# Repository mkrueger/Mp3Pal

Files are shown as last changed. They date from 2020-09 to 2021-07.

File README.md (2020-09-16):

# MP3Pal
MP3 player for kids based tonunio and Hörbert design.



## Features

 * Plays audio from a SD Card
 * Select playlists via 12 buttons and rfid tags

## Part list

* Arduino Nano
* DFPlayer mini
* Speaker Visaton FR 10 HM
* Guitar Potentiometer
* 74HC238, 74HC153
* 9 Arcade buttons + 3 Acracde buttons with LED
* AZDelivery Battery Expansion Shield 18650
* 18650 Battery
* Göldo Dome Chrome
* Handle from DIY Store
* Resistors 5x 10k, 1x 1k, 3x 100
* 1 Capacitor 100 uF (optional)
* RFID tags, magnets and figures
* Threads for 3D prints (I use the ones from Ruthex) M2, M3, M4
* Wires
  - JST 2.5 Connectors & Wires
  - Mini Micro JST 2.0 (with cables & pin connectors)

… to be continued (but it's below 100 Euro - if you get it from ali express it's maybe ~50)

## Schematic
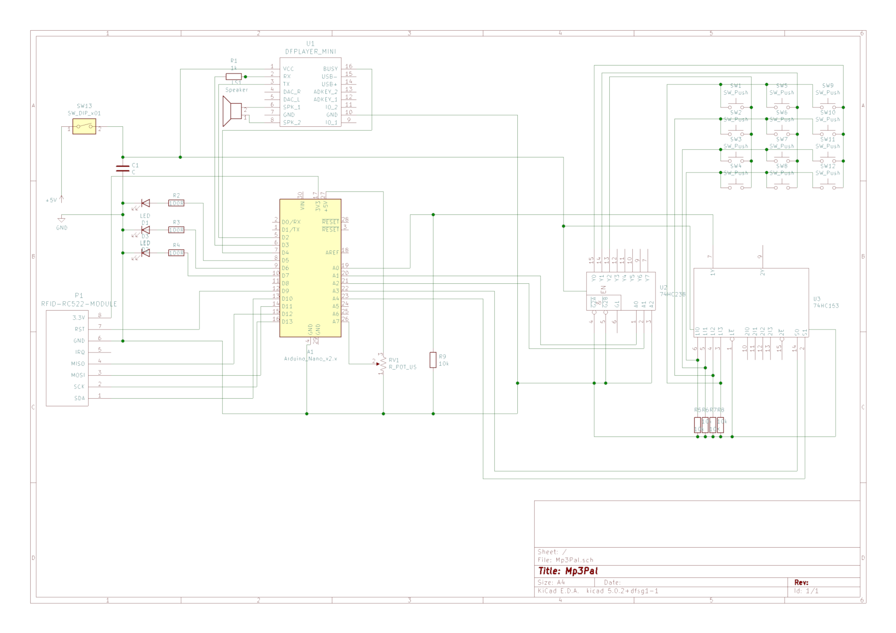
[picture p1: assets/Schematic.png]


## Alternatives

Tonunio

https://www.voss.earth/tonuino/

KidsMP3Player

https://github.com/ghmartin77/KidsMP3Player

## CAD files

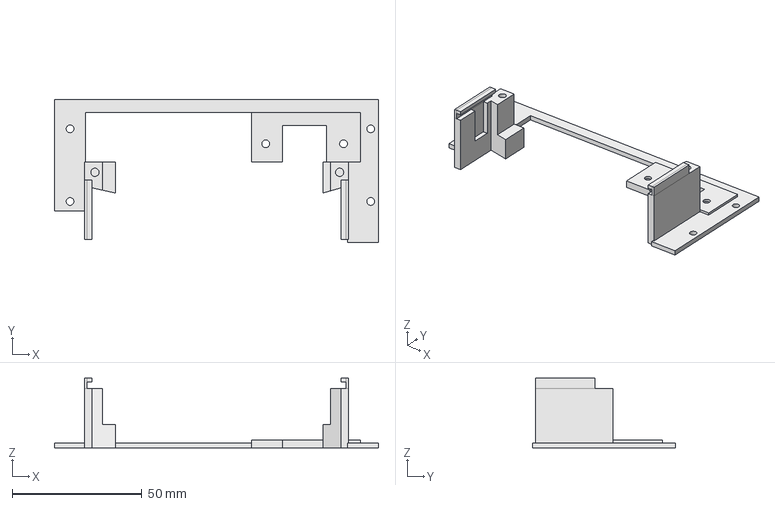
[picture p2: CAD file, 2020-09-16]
CAD_Files/v1/BattryMount.FCStd
125.0 x 55.0 x 27.0 mm

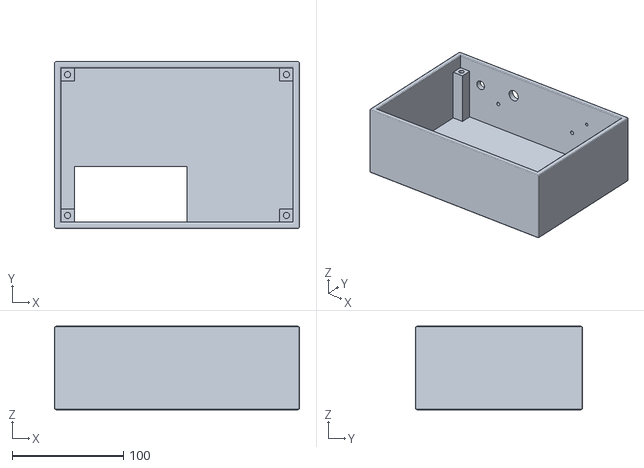
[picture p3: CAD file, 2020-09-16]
Production/Chassis.stl
220.0 x 150.0 x 75.0

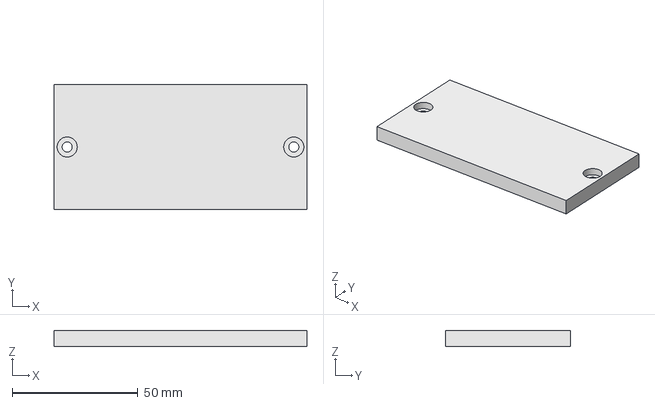
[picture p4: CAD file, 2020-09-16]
CAD_Files/v1/Backplate.FCStd
100.5 x 49.5 x 6.50 mm

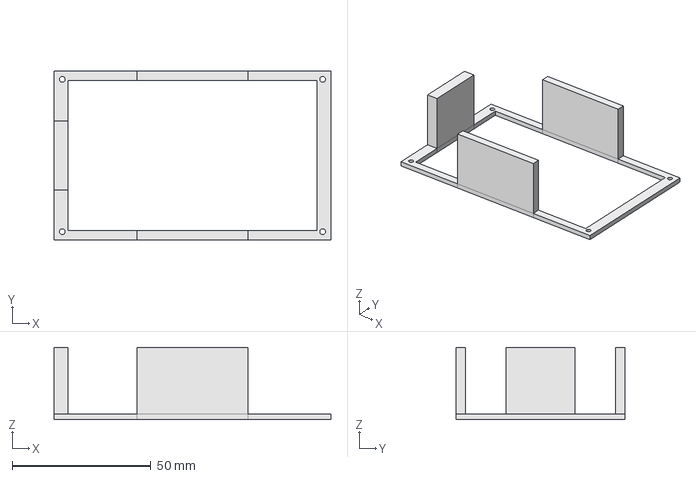
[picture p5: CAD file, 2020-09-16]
CAD_Files/v1/PcbMount.FCStd
100.0 x 61.0 x 26.0 mm

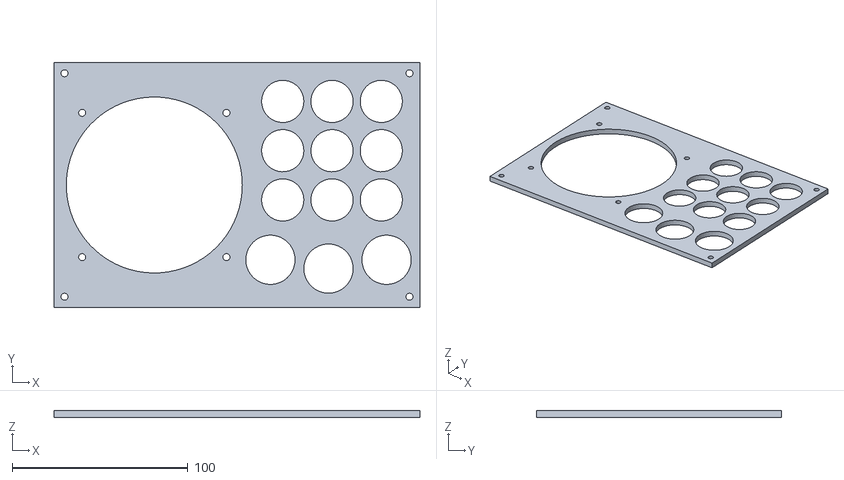
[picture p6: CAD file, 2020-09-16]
Production/Frontplate.stl
208.0 x 139.0 x 4.00

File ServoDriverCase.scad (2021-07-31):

include <arduino/arduino.scad>

$fn=40;
wallsize=4;

boxW=84+wallsize;
boxL=106+wallsize;
boxH=25;

minkowski()
{
    translate([-boxW/2,-boxL/2,0])
    {
       difference() {
           difference() {
              cube([boxW,boxL,boxH], center=false);
              translate([boxW-27,boxL-wallsize-1,7])
                cube([16,wallsize+6, boxH]);
              translate([boxW-55,boxL-wallsize-1,7])
                cube([12,wallsize+2, boxH]);
           }
            translate([wallsize,wallsize,wallsize])
                cube([boxW-wallsize*2,boxL-wallsize*2,boxH], center=false);
        }
    }
    sphere(1);
}

difference() {
    translate([0, 0, boxH])
        cube([boxW-wallsize,boxL-wallsize, wallsize*2], center=true);
    
    translate([0, 0, boxH+0.1])
        cube([boxW-wallsize*2,boxL-wallsize*2, wallsize*2+0.3], center=true);
}

translate ([boxW/2-wallsize,boxL/2-wallsize,0]) {
    rotate(a=[0,0,180]) {
        translate([2.54,15.24,wallsize])
            mount();
        translate([50.8,13.97,wallsize])
            mount();
        translate([2.54,90.17,wallsize])
            mount();
        translate([50.8,96.52,wallsize])
            mount();
        /*
        translate([0,0,wallsize+5])
            arduino(MEGA);*/
    }
}

translate ([4-boxW/2 + wallsize,62+-boxL+wallsize,0]) {
        translate([0,0,wallsize])
            mount();
        translate([18,0,wallsize])
            mount();
        translate([0,55,wallsize])
            mount();
        translate([18,55,wallsize])
            mount();
}
module mount() {
    difference() {
        cylinder(h=5,d=3.2 + 1.4 * 2);
        translate([0, 0, 1.1])
            cylinder(h=4.1, d=3.2);
    }
}

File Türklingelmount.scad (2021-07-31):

$fn=100;

backplateHeight=184;
backplateWidth=105;

depth  = 2;

difference()
{
    cube([backplateWidth, backplateHeight, depth], center = true);
    translate([-55 / 2, -142 / 2, 0])
        cylinder(depth, r=2, center = true);
    translate([55 / 2, -142 / 2, 0])
        cylinder(depth, r=2, center = true);
    translate([-55 / 2, 142 / 2, 0])
        cylinder(depth, r=2, center = true);
    translate([55 / 2,  142 / 2, 0])
        cylinder(depth, r=2, center = true);
    
   translate([0, -68 / 2, 0])
        cylinder(depth, r=2, center = true);
   translate([0, 68 / 2, 0])
        cylinder(depth, r=2, center = true);
   
    cube([25, 30, depth], center = true);

}

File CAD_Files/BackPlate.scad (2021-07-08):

$fn=100;

spacing = 1;
backplateHeight=78;
backplateWidth=97;

depth  = 6;
sinkHeight = 3.5;

difference()
{
    cube([backplateWidth - spacing, backplateHeight - spacing , 4], center = true);
    translate([-backplateWidth / 2 + 6, 0, 0])
        cylinder(depth, r=2, center = true);
    translate([backplateWidth / 2 - 6, 0, 0])
        cylinder(depth, r=2, center = true);
   
    translate([0, 0, depth - sinkHeight])
    {
        translate([-backplateWidth / 2 + 6, 0, 0])
            cylinder(sinkHeight, r=4, center = true);
        translate([backplateWidth / 2 - 6, 0, 0])
            cylinder(sinkHeight, r=4, center = true);
    }

}

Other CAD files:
Production/Backplate.stl
CAD_Files/v1/Chassis.FCStd
Production/PcbMount.stl
CAD_Files/v1/Frontplate.FCStd
Production/BatteryMount.stl
CAD_Files/BatteryMount.scad
CAD_Files/Chassis.scad
CAD_Files/FrontPlate.scad
CAD_Files/Unbenannt.scad

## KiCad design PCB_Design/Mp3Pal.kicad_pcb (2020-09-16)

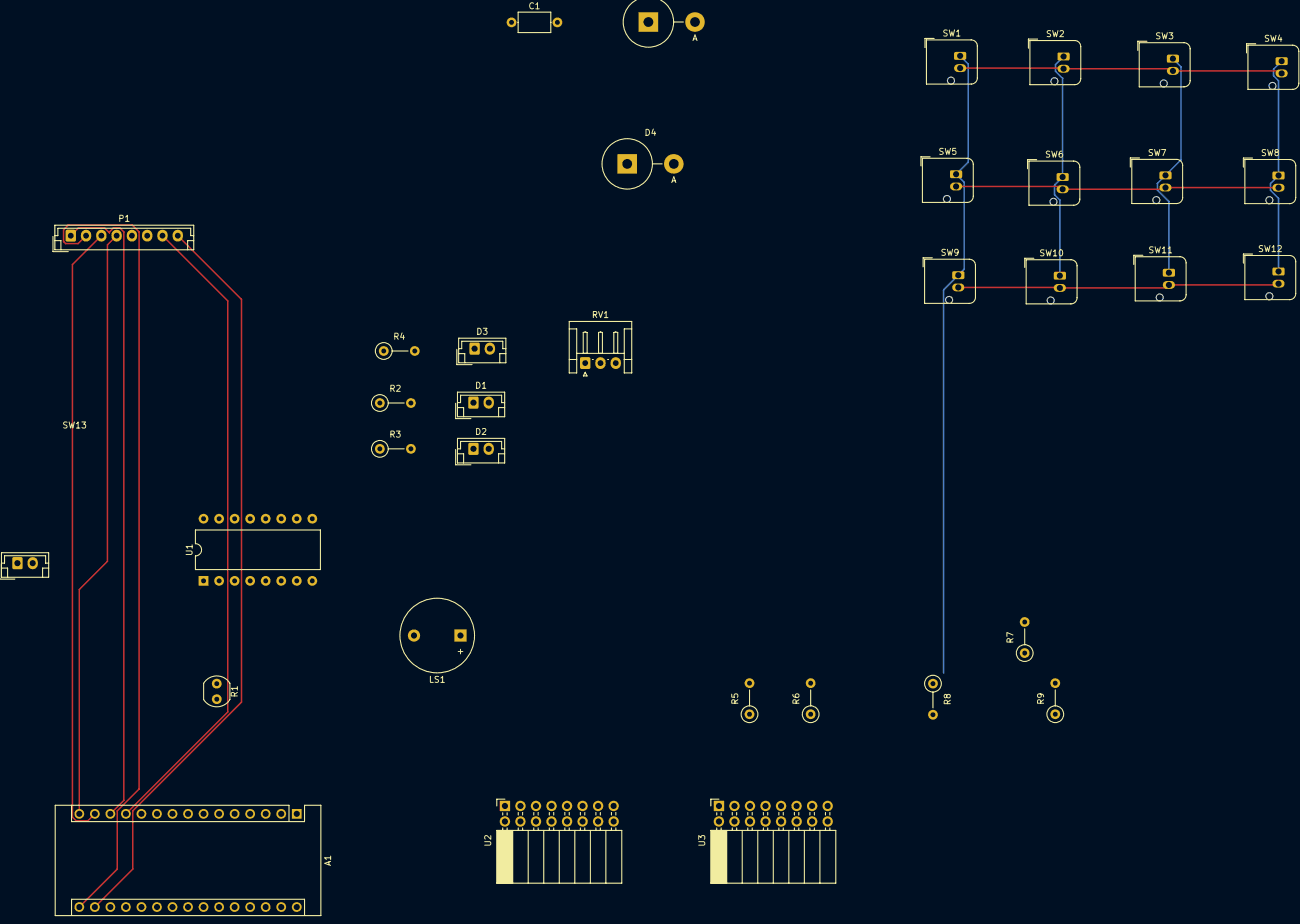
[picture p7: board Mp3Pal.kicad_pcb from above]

Board: 2 copper layers, 35 parts (0 on the bottom side), 34 nets.

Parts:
A1: Arduino_Nano_v2.x; Arduino_Nano
C1: C; C_Axial_L5.1mm_D3.1mm_P7.50mm_Horizontal
D1, D2, D3: LED; JST_EH_B2B-EH-A_1x02_P2.50mm_Vertical
D4, D5: D; D_5KPW_P7.62mm_Vertical_AnodeUp
LS1: Speaker; Buzzer_12x9.5RM7.6
P1: RFID-RC522-MODULE; JST_EH_B8B-EH-A_1x08_P2.50mm_Vertical
R1: 1k; R_LDR_4.9x4.2mm_P2.54mm_Vertical
R2, R3, R4: 100R; R_Axial_DIN0207_L6.3mm_D2.5mm_P5.08mm_Vertical
R5, R6, R8, R9: 10k; R_Axial_DIN0207_L6.3mm_D2.5mm_P5.08mm_Vertical
R7: R; R_Axial_DIN0207_L6.3mm_D2.5mm_P5.08mm_Vertical
RV1: R_POT_US; JST_EH_S3B-EH_1x03_P2.50mm_Horizontal
SW1, SW2, SW3, SW4, SW5, SW6, SW7, SW8, SW9, SW10, SW11, SW12: SW_Push; JST_JWPF_B02B-JWPF-SK-R_1x02_P2.00mm_Vertical
SW13: SW_DIP_x01; JST_EH_B2B-EH-A_1x02_P2.50mm_Vertical
U1: DFPLAYER_MINI; DIP-16_W10.16mm
U2: 74HC238; PinSocket_2x08_P2.54mm_Horizontal
U3: 74HC153; PinSocket_2x08_P2.54mm_Horizontal

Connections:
GND: A1.4, C1.2, D1.1, D2.1, D3.1, D4.1, D5.1, D5.2, R5.2, R6.2, R7.2, R8.2, R9.2, RV1.1, U2.3, U2.4, U2.5, U2.8, U3.1, U3.8
unnamed: A1.5, U1.3
unnamed: A1.6, R1.2
unnamed: A1.7, U1.16
unnamed: A1.9, R4.2
unnamed: A1.10, R3.2
unnamed: A1.11, R2.2
unnamed: A1.12, P1.7
unnamed: A1.13, P1.1
unnamed: A1.14, P1.3
unnamed: A1.15, P1.4
unnamed: A1.16, P1.2
unnamed: A1.17, P1.8
unnamed: A1.19, U2.1
unnamed: A1.20, U2.2
unnamed: A1.21, U3.14
unnamed: A1.22, U3.2
unnamed: A1.23, R9.1, U3.7
unnamed: A1.26, RV1.2
unnamed: D1.2, R2.1
unnamed: D2.2, R3.1
unnamed: D3.2, R4.1
unnamed: D4.2, U1.7
unnamed: LS1.1, U1.8
unnamed: LS1.2, U1.6
unnamed: R1.1, U1.2
unnamed: R5.1, SW4.1, SW8.1, SW12.1, U3.6
unnamed: R6.1, SW3.1, SW7.1, SW11.1, U3.5
unnamed: R7.1, SW2.1, SW6.1, SW10.1, U3.4
unnamed: R8.1, SW1.1, SW5.1, SW9.1, U3.3
unnamed: SW1.2, SW2.2, SW3.2, SW4.2, U2.13
unnamed: SW5.2, SW6.2, SW7.2, SW8.2, U2.14
unnamed: SW9.2, SW10.2, SW11.2, SW12.2, U2.15
VCC: A1.30, C1.1, P1.6, RV1.3, SW13.2, U1.1, U2.16, U3.16

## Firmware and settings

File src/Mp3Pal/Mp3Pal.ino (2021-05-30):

#include "Arduino.h"
#include "SoftwareSerial.h"
#include <DFMiniMp3.h>

#include <math.h>
#include <SPI.h>
#include <MFRC522.h>
#include "Parameters.h"

MFRC522 mfrc522(SS_PIN, RST_PIN); // Create MFRC522 instance.

SoftwareSerial mySoftwareSerial(2, 3);

int16_t currentTrack = -1;
int16_t currentFolder = -1;
int16_t trackCount;

bool isPause = false;
unsigned long nowMs;

class Mp3Notify;

static DFMiniMp3<SoftwareSerial, Mp3Notify> mp3Player(mySoftwareSerial);

#include "Functions.h"
#include "Volume.h"
#include "Keypad.h"

void setup()
{
  pinMode(LED_PAUSE_PIN, OUTPUT);
  digitalWrite(LED_PAUSE_PIN, HIGH);
  pinMode(LED_NEXT_PIN, OUTPUT);
  pinMode(LED_PREV_PIN, OUTPUT);

  pinMode(outPinA0, OUTPUT);
  pinMode(outPinA1, OUTPUT);
  pinMode(outPinS0, OUTPUT);
  pinMode(outPinS1, OUTPUT);
  pinMode(inPinY, INPUT);

  pinMode(PIN_VOLUME, INPUT);
  pinMode(PIN_BUSY, INPUT);

  mySoftwareSerial.begin(9600);
  Serial.begin(115200);
  SPI.begin();
  mfrc522.PCD_Init();
  mp3Player.begin();
/*  if (!mp3Player.begin(mySoftwareSerial))
  {
    Serial << F("Fatal error starting the mp3 player module.") << endl
           << F("Please restart.") << endl;
    errorMode();
  }
*/
  keyReadMs = volumeReadMs = millis();
  mp3Player.setVolume(7);
  volumeReadMs = -VOLUME_CHECK_TIMEOUT;

  Serial << F("MP3Pal online.") << endl;
  playStartAnimation();
}

void loop()
{
  nowMs = millis();
/*  if (mp3Player.available())
  {
    printDetail(mp3Player.readType(), mp3Player.read());
  }*/
  updateVolume();
  handleKeypress();
  scanRfid();
  delay(20);
}

/*
void printDetail(uint8_t type, int value)
{
  switch (type)
  {
  case TimeOut:
    Serial << F("Time Out!") << endl;
    mp3Player.reset();
    break;
  case WrongStack:
    Serial << F("Stack Wrong!") << endl;
    break;
  case DFPlayerCardInserted:
    Serial << F("Card Inserted!") << endl;
    break;
  case DFPlayerCardRemoved:
    Serial << F("Card Removed!") << endl;
    break;
  case DFPlayerCardOnline:
    Serial << F("Card Online!") << endl;
    break;
  case DFPlayerPlayFinished:
    Serial << F("Number:") << currentTrack << F(" Play Finished!");
    skipTrack();
    break;
  case DFPlayerError:
    Serial << F("DFPlayerError:");
    switch (value)
    {
    case Busy:
      Serial << F("Card not found");
      errorMode();
      break;
    case Sleeping:
      Serial << F("Sleeping");
      break;
    case SerialWrongStack:
      Serial << F("Get Wrong Stack");
      break;
    case CheckSumNotMatch:
      Serial << F("Check Sum Not Match");
      break;
    case FileIndexOut:
      Serial << F("File Index Out of Bound");
      break;
    case FileMismatch:
      Serial << F("Cannot Find File");
      break;
    case Advertise:
      Serial << F("In Advertise");
      break;
    default:
      Serial << F("Unknown");
      break;
    }
    Serial << endl;
    break;
  default:
    break;
  }
}
*/

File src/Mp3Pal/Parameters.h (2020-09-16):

#ifndef PARAMETERS_H
#define PARAMETERS_H


#define PIN_BUSY 4

#define LED_NEXT_PIN 6
#define LED_PREV_PIN 8
#define LED_PAUSE_PIN 7

#define SS_PIN 10
#define RST_PIN 9

#define endl F("\n")
template <class T>
inline Stream &operator<<(Stream &stream, T arg)
{
    stream.print(arg);
    return stream;
}

// hack: mp3Player.readFileCountsInFolder always returns - 1 so I hard coded the track counts
const int16_t TRACK_COUNT[] = {4, 4, 4, 5, 5, 5, 5, 5, 9, 3, 4, 5};

// Hard coded UID Tokens
String uidTags[] = {
  "79 E8 87 98",
  "BA 5F 3B 86"
};

const uint8_t uidPlaylists[] = { 10, 11};

#endif

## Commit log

2021-05-31 Worked on chassis design.
    [BackPlate.scad, Chassis.scad, FrontPlate.scad]
2021-07-08 Added old design, improved cad designs
    [BackPlate.scad, Backplate.FCStd, BatteryMount.scad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]
